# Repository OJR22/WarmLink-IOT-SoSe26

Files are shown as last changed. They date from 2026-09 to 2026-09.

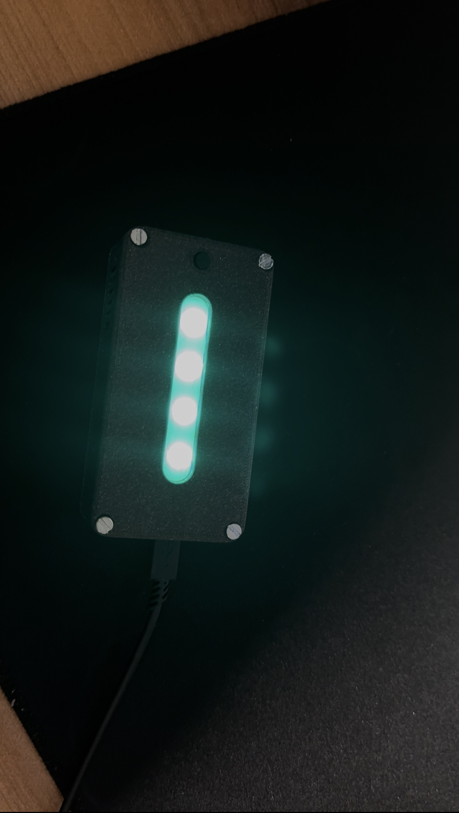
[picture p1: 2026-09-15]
IMG_9581.png

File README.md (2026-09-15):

# WarmLink

Wärme spüren über Distanz. Ein IoT-Prototyp, der zwei Personen an
unterschiedlichen Orten über die gemessene Raumtemperatur und einen
kurzen Lichtimpuls miteinander verbindet.

Dieses Repository enthält alles, was benötigt wird, um WarmLink
selbst nachzubauen: Bauteilliste, Verkabelung, Firmware und Gehäuse.

## Inhaltsverzeichnis

- [Was ist WarmLink](#was-ist-warmlink)
- [Benötigte Bauteile](#benötigte-bauteile)
- [Verkabelung](#verkabelung)
- [Firmware aufspielen](#firmware-aufspielen)
- [MQTT-Broker einrichten](#mqtt-broker-einrichten)
- [Gehäuse drucken](#gehäuse-drucken)
- [Zusammenbau](#zusammenbau)
- [Bedienung](#bedienung)
- [Bekannte Probleme](#bekannte-probleme)

## Was ist WarmLink

WarmLink besteht aus zwei baugleichen Endpunkten. Jeder Endpunkt
misst die Umgebungstemperatur und Luftfeuchtigkeit und sendet die
Werte über MQTT an den jeweils anderen Endpunkt. Dort wird die
empfangene Temperatur über eine RGB-LED farblich dargestellt (blau
bei kalt bis rot bei warm). Über einen Taster kann zusätzlich ein
kurzer weißer Lichtimpuls an die Gegenseite gesendet werden, um
bewusst ein Zeichen der Verbundenheit zu setzen.

## Benötigte Bauteile

Für das komplette WarmLink System werden **zwei baugleiche
Endpunkte** benötigt. Jedes Bauteil wird daher zweimal gebraucht:

| Bauteil | Menge gesamt | Bemerkung |
|---|---|---|
| ESP8266 NodeMCU (Crowtail) | 2 (1 pro Endpunkt) | Mikrocontroller mit WLAN |
| Temperatur-/Feuchtigkeitssensor (DHT11, Crowtail) | 2 (1 pro Endpunkt) | physischer Input |
| RGB-LED-Modul (WS2812B, Crowtail) | 2 (1 pro Endpunkt) | physischer Output |
| Taster (Crowtail Button) | 2 (1 pro Endpunkt) | Verbundenheits-Signal |
| Micro-USB-Kabel + 5V-Netzteil | 2 (1 pro Endpunkt) | Stromversorgung |
| Gehäuse (3D-gedruckt) | 2 (1 pro Endpunkt) | siehe WARMLINK_BOX.stl |
| Button-Verlängerung (3D-gedruckt) | 2 (1 pro Endpunkt) | siehe WARMLINK_BUTTON.stl |
| Milchglas / Plexiglas-Streifen | 2 (1 pro Endpunkt) | als Lichtdiffusor hinter dem LED-Fenster im Deckel, passend zugeschnitten |

Zusätzlich, einmalig für das gesamte System:

- Ein Computer im selben WLAN, auf dem ein MQTT-Broker läuft
- 3D-Drucker (für die Gehäuse)

## Verkabelung

Beide Endpunkte werden identisch verkabelt:

| Bauteil | Pin am NodeMCU |
|---|---|
| Temperatursensor | D3 |
| RGB-LED | D1 |
| Taster | D2 |

Alle Module nutzen die 4-poligen Crowtail-Stecker und werden einfach
in die entsprechenden Ports auf dem Base-Shield gesteckt.

## Firmware aufspielen

1. [Arduino IDE](https://www.arduino.cc/en/software) installieren
2. In der Arduino IDE unter **Werkzeuge → Board → Boardverwalter**
   nach `esp8266` suchen und das Paket "esp8266 by ESP8266
   Community" installieren
3. Unter **Werkzeuge → Bibliotheken verwalten** folgende
   Bibliotheken installieren:
   - `PubSubClient` (Nick O'Leary)
   - `DHT sensor library` (Adafruit, inkl. Abhängigkeit "Adafruit
     Unified Sensor")
   - `Adafruit NeoPixel`
4. Die passende Firmware-Datei aus diesem Repository öffnen:
   - [`warmlink_endpoint1.ino`](warmlink_endpoint1.ino) für den
     ersten Endpunkt
   - [`warmlink_endpoint2.ino`](warmlink_endpoint2.ino) für den
     zweiten Endpunkt
5. Im Code folgende Zeilen an die eigene Umgebung anpassen:
   ```cpp
   const char* WIFI_SSID     = "DEIN_WLAN_NAME";
   const char* WIFI_PASSWORD = "DEIN_WLAN_PASSWORT";
   const char* MQTT_BROKER   = "IP_DEINES_BROKER_RECHNERS";
   ```
6. Board auswählen: **Werkzeuge → Board → NodeMCU 1.0 (ESP-12E
   Module)**
7. Passenden COM-Port auswählen und hochladen

## MQTT-Broker einrichten

WarmLink benötigt einen MQTT-Broker im lokalen Netzwerk. Empfohlen
wird [Mosquitto](https://mosquitto.org/download/):

1. Mosquitto installieren
2. In der Datei `mosquitto.conf` folgende Zeilen ergänzen, damit der
   Broker auch für andere Geräte im Netzwerk erreichbar ist:
   ```
   listener 1883
   allow_anonymous true
   ```
3. Broker starten:
   ```
   mosquitto -v -c mosquitto.conf
   ```
4. In der Windows-Firewall eingehende Verbindungen auf Port 1883
   erlauben

## Gehäuse drucken

Die fertigen, druckbereiten Modelle liegen als STL-Dateien in diesem
Repository bereit:

- [`WARMLINK_BOX.stl`](WARMLINK_BOX.stl) – das Hauptgehäuse
- [`WARMLINK_BUTTON.stl`](WARMLINK_BUTTON.stl) – die Verlängerung
  für den Taster

Beide Dateien einfach in einen Slicer (z. B. Cura, PrusaSlicer)
laden und mit PLA drucken (empfohlen: 0,2 mm Schichthöhe, 15-20%
Infill). Für jeden Endpunkt wird je ein Satz benötigt, WARMLINK_BOX.stl
und WARMLINK_BUTTON.stl also jeweils zweimal drucken.

## Zusammenbau

1. Sensor, LED und Taster wie oben beschrieben mit dem NodeMCU
   verbinden
2. Sensor stehend im Inneren an die vorgesehene Halterung kleben,
   mit der Sensorfläche in Richtung der Lüftungsschlitze
3. NodeMCU im Boden platzieren, USB-Anschluss zur seitlichen Öffnung
   ausrichten
4. Milchglas- bzw. Plexiglas-Streifen passend zugeschnitten in die
   Führungsschiene im Deckel-Fenster schieben, damit sich das
   LED-Licht gleichmäßiger verteilt
5. RGB-LED mit Heißkleber oder doppelseitigem Klebeband unter dem
   Diffusor befestigen (Kabel vorher anschließen!)
6. Taster mit der gedruckten Verlängerung durch die runde Öffnung in
   der Seitenwand stecken
7. Deckel auf den Boden setzen und mit vier Schrauben fixieren

## Bedienung

1. Beide Endpunkte mit Strom versorgen (USB-Netzteil)
2. Beide Endpunkte verbinden sich automatisch mit dem hinterlegten
   WLAN und dem MQTT-Broker
3. Die LED zeigt nach kurzer Zeit die Temperatur der Gegenseite an
4. Ein Druck auf den Taster löst einen kurzen weißen Lichtimpuls auf
   der LED des anderen Endpunkts aus

## Bekannte Probleme

- **ESP8266 verbindet sich nicht mit dem WLAN:** Der ESP8266
  unterstützt ausschließlich 2,4-GHz-WLAN mit WPA2-Verschlüsselung.
  Moderne Router mit WPA3 oder reinem 5-GHz-Band führen zu
  Verbindungsproblemen.
- **RGB-LED verursacht WLAN-Aussetzer:** Bei knapper
  Stromversorgung kann die LED beim Ansteuern kurzzeitig die
  WLAN-Verbindung stören. Abhilfe schafft eine Reduzierung der
  LED-Helligkeit im Code über `strip.setBrightness(80)` (Wertebereich
  0 bis 255) sowie ein stabiles Netzteil.
- **MQTT-Verbindung schlägt fehl, obwohl WLAN steht:** Meist liegt
  es daran, dass der Broker nicht für Netzwerkverbindungen
  konfiguriert ist (siehe Abschnitt MQTT-Broker einrichten) oder die
  Windows-Firewall den Port blockiert.

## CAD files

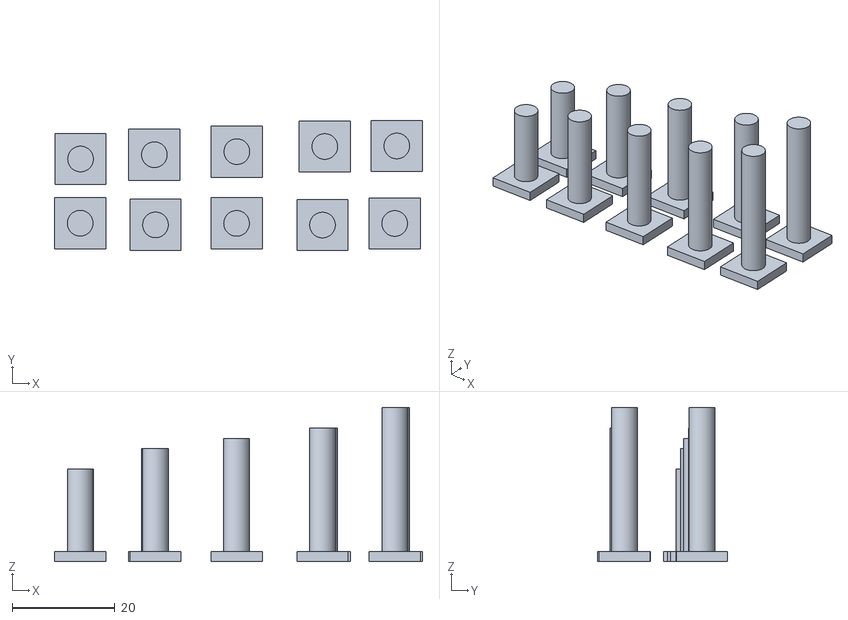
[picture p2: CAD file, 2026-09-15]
WARMLINK_BUTTON.stl
71.7 x 25.4 x 30.0

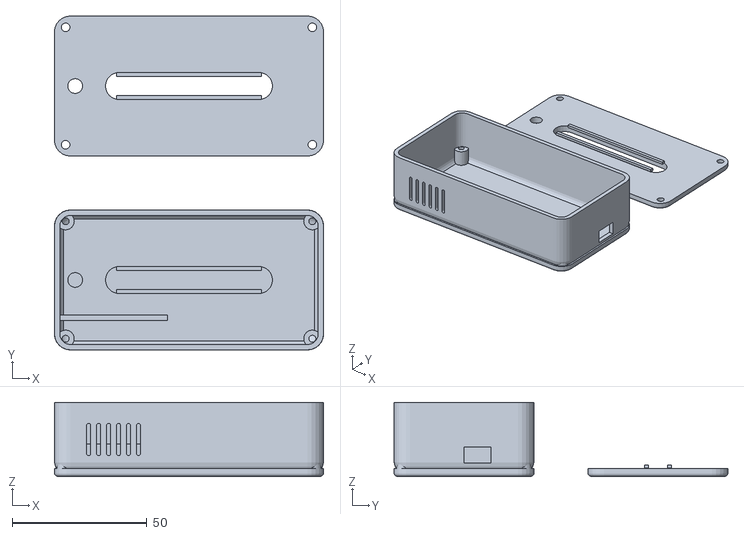
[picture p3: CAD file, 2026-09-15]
WARMLINK_BOX.stl
100.0 x 124.0 x 27.5

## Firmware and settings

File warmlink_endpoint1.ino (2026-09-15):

/*
  WarmLink - Endpunkt 1
  Liest Temperatur und Feuchtigkeit, sendet und empfaengt Werte per
  MQTT, zeigt Temperatur der Gegenseite per LED an, Button sendet
  einen Verbundenheits-Puls.
*/

#include <ESP8266WiFi.h>
#include <PubSubClient.h>
#include <DHT.h>
#include <Adafruit_NeoPixel.h>

// ==================== KONFIGURATION ====================
#define ENDPOINT_ID 1

// WLAN-Zugangsdaten
const char* WIFI_SSID     = "DEIN_WLAN_NAME";
const char* WIFI_PASSWORD = "DEIN_WLAN_PASSWORT";

// MQTT-Broker
const char* MQTT_BROKER   = "192.168.0.100";
const int   MQTT_PORT     = 1883;

// Pins
#define DHT_PIN       D3     // Temperatursensor
#define DHT_TYPE      DHT11
#define LED_PIN       D1     // RGB-LED
#define LED_COUNT     4
#define BUTTON_PIN    D2     // Button

// =========================================================

String OWN_TOPIC     = "warmlink/endpoint" + String(ENDPOINT_ID) + "/temp";
String OTHER_TOPIC   = "warmlink/endpoint" + String(ENDPOINT_ID == 1 ? 2 : 1) + "/temp";
String OWN_HUMIDITY  = "warmlink/endpoint" + String(ENDPOINT_ID) + "/humidity";
String OWN_PULSE     = "warmlink/endpoint" + String(ENDPOINT_ID) + "/pulse";
String OTHER_PULSE   = "warmlink/endpoint" + String(ENDPOINT_ID == 1 ? 2 : 1) + "/pulse";

DHT dht(DHT_PIN, DHT_TYPE);
Adafruit_NeoPixel strip(LED_COUNT, LED_PIN, NEO_GRB + NEO_KHZ800);

WiFiClient espClient;
PubSubClient mqttClient(espClient);

float receivedTemp = 20.0;
unsigned long lastSendTime = 0;
const unsigned long SEND_INTERVAL = 8000;

bool pulseReceived = false;
bool lastButtonState = false;

// WLAN verbinden
void connectWiFi() {
  WiFi.mode(WIFI_STA);
  WiFi.setSleepMode(WIFI_NONE_SLEEP);

  Serial.print("Verbinde mit WLAN: ");
  Serial.println(WIFI_SSID);
  WiFi.begin(WIFI_SSID, WIFI_PASSWORD);

  while (WiFi.status() != WL_CONNECTED) {
    delay(500);
    Serial.print(".");
  }
  Serial.println("\nWLAN verbunden! IP-Adresse: " + WiFi.localIP().toString());
}

// MQTT Nachricht empfangen
void onMqttMessage(char* topic, byte* payload, unsigned int length) {
  String message;
  for (unsigned int i = 0; i < length; i++) {
    message += (char)payload[i];
  }

  String topicStr = String(topic);
  Serial.println("Nachricht empfangen [" + topicStr + "]: " + message);

  if (topicStr == OTHER_TOPIC) {
    receivedTemp = message.toFloat();
  } else if (topicStr == OTHER_PULSE) {
    pulseReceived = true;
  }
}

// MQTT verbinden
void connectMqtt() {
  while (!mqttClient.connected()) {
    Serial.print("Verbinde mit MQTT-Broker...");
    String clientId = "WarmLinkEndpoint" + String(ENDPOINT_ID);

    if (mqttClient.connect(clientId.c_str())) {
      Serial.println(" verbunden!");
      mqttClient.subscribe(OTHER_TOPIC.c_str());
      mqttClient.subscribe(OTHER_PULSE.c_str());
      Serial.println("Abonniert: " + OTHER_TOPIC + " und " + OTHER_PULSE);
    } else {
      Serial.print(" fehlgeschlagen, Fehlercode=");
      Serial.print(mqttClient.state());
      Serial.println(" -> neuer Versuch in 3 Sekunden");
      delay(3000);
    }
  }
}

// Temperatur in Farbe umrechnen
struct ColorStop { float temp; int r, g, b; };
ColorStop colorStops[] = {
  {0.0,    0,   0, 255},
  {10.0,   0, 255,   0},
  {20.0, 255, 255,   0},
  {30.0, 255, 140,   0},
  {40.0, 255,   0,   0}
};
const int NUM_STOPS = 5;

uint32_t temperatureToColor(float temp) {
  temp = constrain(temp, colorStops[0].temp, colorStops[NUM_STOPS - 1].temp);
  for (int i = 0; i < NUM_STOPS - 1; i++) {
    if (temp >= colorStops[i].temp && temp <= colorStops[i + 1].temp) {
      float range = colorStops[i + 1].temp - colorStops[i].temp;
      float ratio = (temp - colorStops[i].temp) / range;
      int r = colorStops[i].r + ratio * (colorStops[i + 1].r - colorStops[i].r);
      int g = colorStops[i].g + ratio * (colorStops[i + 1].g - colorStops[i].g);
      int b = colorStops[i].b + ratio * (colorStops[i + 1].b - colorStops[i].b);
      return strip.Color(r, g, b);
    }
  }
  return strip.Color(255, 255, 255);
}

void updateLed(float temp) {
  uint32_t color = temperatureToColor(temp);
  for (int i = 0; i < LED_COUNT; i++) strip.setPixelColor(i, color);
  strip.show();
}

// Puls-Animation abspielen
void playPulseAnimation() {
  Serial.println("Puls empfangen! Zeige Blink-Animation...");
  for (int i = 0; i < 3; i++) {
    for (int j = 0; j < LED_COUNT; j++) strip.setPixelColor(j, strip.Color(255, 255, 255));
    strip.show();
    delay(200);
    for (int j = 0; j < LED_COUNT; j++) strip.setPixelColor(j, strip.Color(0, 0, 0));
    strip.show();
    delay(200);
  }
  updateLed(receivedTemp);
}

void setup() {
  Serial.begin(115200);
  Serial.println("\nWarmLink Endpunkt " + String(ENDPOINT_ID) + " startet...");

  dht.begin();
  strip.begin();
  strip.setBrightness(80);
  strip.show();

  pinMode(BUTTON_PIN, INPUT);

  connectWiFi();
  mqttClient.setServer(MQTT_BROKER, MQTT_PORT);
  mqttClient.setCallback(onMqttMessage);
  mqttClient.setSocketTimeout(10);
}

void loop() {
  if (!mqttClient.connected()) {
    connectMqtt();
  }
  mqttClient.loop();

  // Eigenen Sensorwert senden
  if (millis() - lastSendTime > SEND_INTERVAL) {
    lastSendTime = millis();

    float ownTemp = dht.readTemperature();
    float ownHumidity = dht.readHumidity();

    if (isnan(ownTemp)) {
      Serial.println("Fehler beim Lesen des Sensors!");
    } else {
      Serial.println("Eigene Temperatur: " + String(ownTemp) + " C");
      String tempString = String(ownTemp, 1);
      mqttClient.publish(OWN_TOPIC.c_str(), tempString.c_str());

      if (!isnan(ownHumidity)) {
        String humString = String(ownHumidity, 1);
        mqttClient.publish(OWN_HUMIDITY.c_str(), humString.c_str());
      }
    }

    updateLed(receivedTemp);
  }

  // Button pruefen
  bool currentButtonState = digitalRead(BUTTON_PIN);
  if (currentButtonState && !lastButtonState) {
    Serial.println("Button gedrueckt! Sende Puls...");
    mqttClient.publish(OWN_PULSE.c_str(), "1");
  }
  lastButtonState = currentButtonState;

  // Empfangenen Puls abspielen
  if (pulseReceived) {
    pulseReceived = false;
    playPulseAnimation();
  }
}
